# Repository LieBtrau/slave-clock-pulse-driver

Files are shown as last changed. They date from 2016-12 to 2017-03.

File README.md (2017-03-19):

# slave-clock-pulse-driver
Hardware and firmware to make slave clocks run autonomously

In public offices and vessels slave clocks are used for timekeeping.  These clocks need impulses from a master clock to advance.  To make a slave clock run autonomously, a pulse driver is needed.  That is exactly what the hardware in this project will be doing.

An [MCS-973C1](http://media.wix.com/ugd/56d64c_fa3401d1265442198025946bb6db4be5.pdf) slave clock from Marine Radio Co., Ltd. Korea will equipped with the pulse driver.

# Reading on...
More info can be found on the [Wiki](../../wiki).

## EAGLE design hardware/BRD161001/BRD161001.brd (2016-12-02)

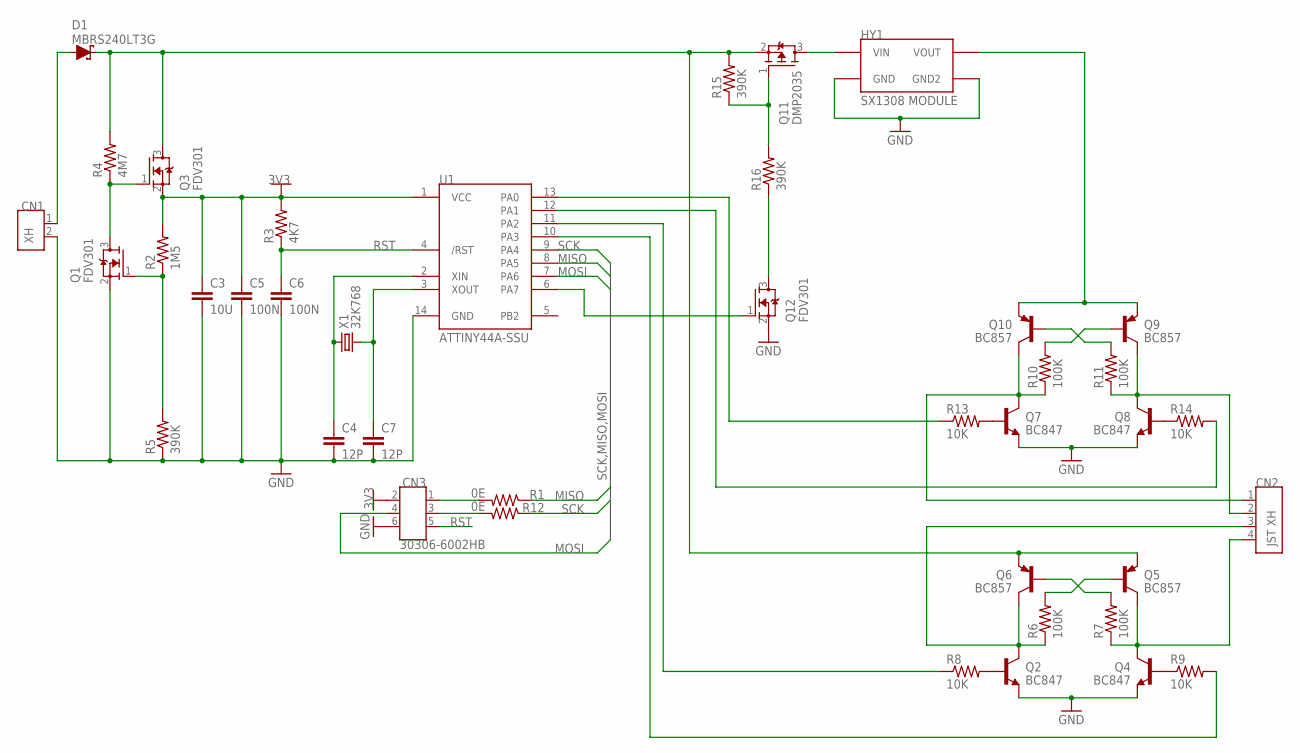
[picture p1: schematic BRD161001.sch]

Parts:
C3: 10U; CA_1206
C4, C7: 12P; CA_0603
C5, C6: 100N; CA_1206
CN1: XH; CN_HDR1X2_180D_P25_JST_B2B-XH
CN2: JST XH; CN_HDR1X4_180D_P25_JST_B4B-XH
CN3: 30306-6002HB; CN_HDR2X3_180D_P25_3M
D1: MBRS240LT3G; DI_DO214AA_SMB
HY1: SX1308 MODULE; HY_SX1308
Q1, Q3, Q12: FDV301; SC_SOT23
Q2, Q4, Q7, Q8: BC847; SC_SOT23
Q5, Q6, Q9, Q10: BC857; SC_SOT23
Q11: DMP2035; SC_SOT23
R1, R12: 0E; RE_1206
R2: 1M5; RE_1206
R3: 4K7; RE_1206
R4: 4M7; RE_1206
R5, R15, R16: 390K; RE_1206
R6, R7, R10, R11: 100K; RE_1206
R8, R9, R13, R14: 10K; RE_1206
U1: ATTINY44A-SSU; SC_SO14
X1: 32K768; XT_3215

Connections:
3V3: C3.1, C5.1, CN3.2, Q3.2 (S), R2.2, R3.2, U1.1 (VCC)
GND: C3.2, C4.2, C5.2, C6.2, C7.2, CN1.2, CN3.6, HY1.GND1 (GND), HY1.GND2, Q1.2 (S), Q2.2 (E), Q4.2 (E), Q7.2 (E), Q8.2 (E), Q12.2 (S), R5.1, U1.14 (GND)
MISO: R1.1, U1.8 (PA5)
MOSI: CN3.4, U1.7 (PA6)
unnamed: CN1.1, D1.A
unnamed: D1.C, Q3.3 (D), Q5.2 (E), Q6.2 (E), Q11.2 (S), R4.2, R15.2
unnamed: Q5.1 (B), R6.2
unnamed: Q1.3 (D), Q3.1 (G), R4.1
unnamed: Q6.1 (B), R7.2
unnamed: Q1.1 (G), R2.1, R5.2
unnamed: C4.1, U1.2 (XIN), X1.1
unnamed: CN2.4, Q4.3 (C), Q5.3 (C), R7.1
unnamed: C7.1, U1.3 (XOUT), X1.2
unnamed: CN2.3, Q2.3 (C), Q6.3 (C), R6.1
unnamed: Q2.1 (B), R8.2
unnamed: Q4.1 (B), R9.1
unnamed: HY1.OUT (VOUT), Q9.2 (E), Q10.2 (E)
unnamed: R9.2, U1.10 (PA3)
unnamed: R8.1, U1.11 (PA2)
unnamed: Q9.1 (B), R10.2
unnamed: Q10.1 (B), R11.2
unnamed: Q7.1 (B), R13.2
unnamed: Q8.1 (B), R14.1
unnamed: R14.2, U1.12 (PA1)
unnamed: Q11.1 (G), R15.1, R16.2
unnamed: CN2.2, Q8.3 (C), Q9.3 (C), R11.1
unnamed: CN2.1, Q7.3 (C), Q10.3 (C), R10.1
unnamed: CN3.1, R1.2
unnamed: CN3.3, R12.2
unnamed: R13.1, U1.13 (PA0)
unnamed: Q12.1 (G), U1.6 (PA7)
unnamed: Q12.3 (D), R16.1
unnamed: HY1.VIN, Q11.3 (D)
RST: C6.1, CN3.5, R3.1, U1.4 (/RST)
SCK: R12.1, U1.9 (PA4)

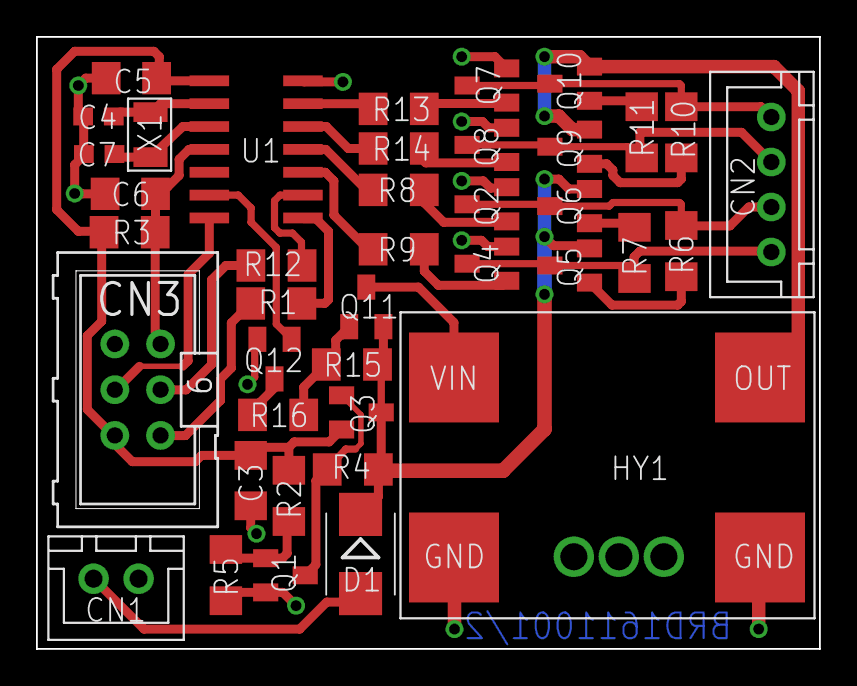
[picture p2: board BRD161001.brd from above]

Board: 2 copper layers, 43.5 x 34.0 mm, 41 parts (0 on the bottom side), 35 nets.

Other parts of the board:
U$2: FR_FRAME_A5

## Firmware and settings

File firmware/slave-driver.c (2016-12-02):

//Register definitions in: /usr/lib/avr/include/avr/iotn44a.h
#include <avr/io.h>                     //needed for port definitions of MCU
#include <avr/interrupt.h>              //needed for interrupts
#include <avr/power.h>                  //needed for power savings settings
#include <util/delay_basic.h>
#include <stdbool.h>

/* Firmware frequency correction
 * -----------------------------
 * Measure the frequency on pin 5 with a decent frequency counter.
 * You should measure 4096.000000 Hz
 * If you measure a higher frequency, then a skip second needs to be added, as in this case.
 * e.g. You measure 4096.0819Hz.  After how many pulses must a pulse be skipped?
 *      Answer: That's the time when the correct clock has generated N pulses.
 *          At that same time our "deviated" clock will have generated N pulses and one skipped pulse.
 *          Some little algebra:
 *              N * T1 = (N+1) * T2, where T1=correct period, T2=the "deviated" period
 *              N / f1 = (N+1) / f2
 *              => N = f1 / (f2-f1) = 4096 / (4096.0819 - 4096) = 50012 (approx)
 *
 */
unsigned long ulPulseCounter;
uint8_t minuteCounter;
const unsigned long SKIP_PULSE=50012;      //skip a pulse after every x pulses.
bool bSecondPhase=false;
bool bMinutePhase=false;

void setup(void)
{
    power_adc_disable();
    power_usi_disable();
    power_timer1_disable();
    OCR0A = 31;                         // 2Hz interrupt frequency
    TCCR0A |= _BV(WGM01);               // CTC mode;
    TCCR0B |= _BV(CS01) | _BV(CS00);    // f(clkio)/64
    TIMSK0 |= _BV(OCIE0A);              // enable interrupt on timer overflow
    DDRA|= _BV(DDA7)|_BV(DDA3)|_BV(DDA2)|_BV(DDA1)|_BV(DDA0); //Set coil control pins as outputs
    ulPulseCounter=0;
    minuteCounter=0;
    sei();
}

void loop(void)
{
}

int main(void)
{
    setup();
    while(1)
    {
        loop();
    }
    return 0;
}

ISR(TIM0_COMPA_vect)
{
    uint8_t Coil=0;
    if(ulPulseCounter++==SKIP_PULSE)
    {
        ulPulseCounter=0;
    }else
    {
        //Set up second hand
        bSecondPhase=!bSecondPhase;
        Coil |= bSecondPhase ? _BV(PORTA2) : _BV(PORTA3);

        //Set up hour/minute hand
        if(minuteCounter++==59)
        {
            minuteCounter=0;
            bMinutePhase=!bMinutePhase;
            Coil |= _BV(PORTA7);//enable power to clock driver
            Coil |= bMinutePhase ? _BV(PORTA0) : _BV(PORTA1);
        }

        //Generate both pulses
        PORTA |= Coil;
        _delay_loop_2(100);
        //stop second pulse
        PORTA &= ~(_BV(PORTA2) | _BV(PORTA3));

        if(Coil && (_BV(PORTA0) | _BV(PORTA1)))
        {
            _delay_loop_2(100);
            //Stop minute pulse
            PORTA &= ~Coil;
        }
    }
}

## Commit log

2016-10-16 BRD161001 R00.0x
    [BRD161001.brd, BRD161001.sch]
2016-10-23 Interrupt at 1s intervals with control of an output
2016-10-30 Detailing power consumption
2016-10-31 updating battery technology
2016-11-13 R1 of the hardware design
    [BRD161001.brd, BRD161001.sch]
2016-12-02 Working version, fully interrupt driven
2016-12-02 working on R2 of PCB
    [BRD161001.brd, BRD161001.sch]
2016-12-02 R2 of BRD161001
    [BRD161001.brd, BRD161001.sch]
